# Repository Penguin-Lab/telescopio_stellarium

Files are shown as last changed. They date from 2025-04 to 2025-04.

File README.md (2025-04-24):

# Automação de telescópio para acompanhamento de corpos celestes com dados vindos do Stellarium
Neste projeto, um telescópio manual na configuração Azimutal foi automatizado para que fosse possível ajustar os ângulos de azimute e altitude a partir de dados do software Stellarium. Abaixo, é possível ver o sistema embarcado no telescópio.

 <p>
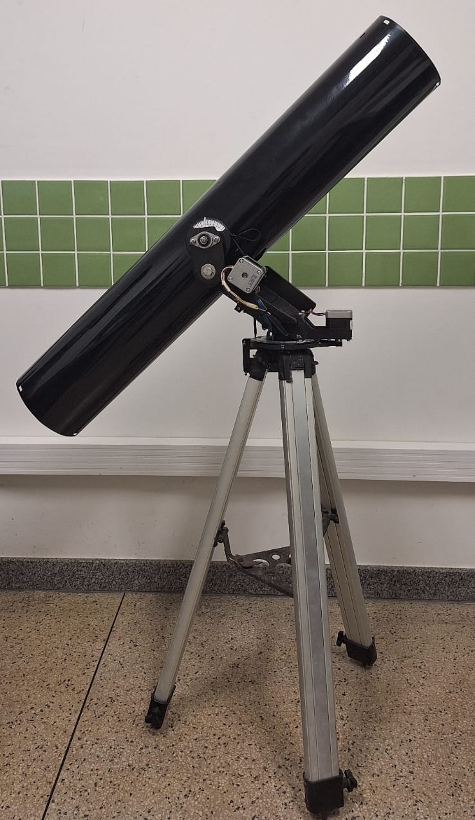
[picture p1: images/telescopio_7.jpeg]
  
</p>

<p>
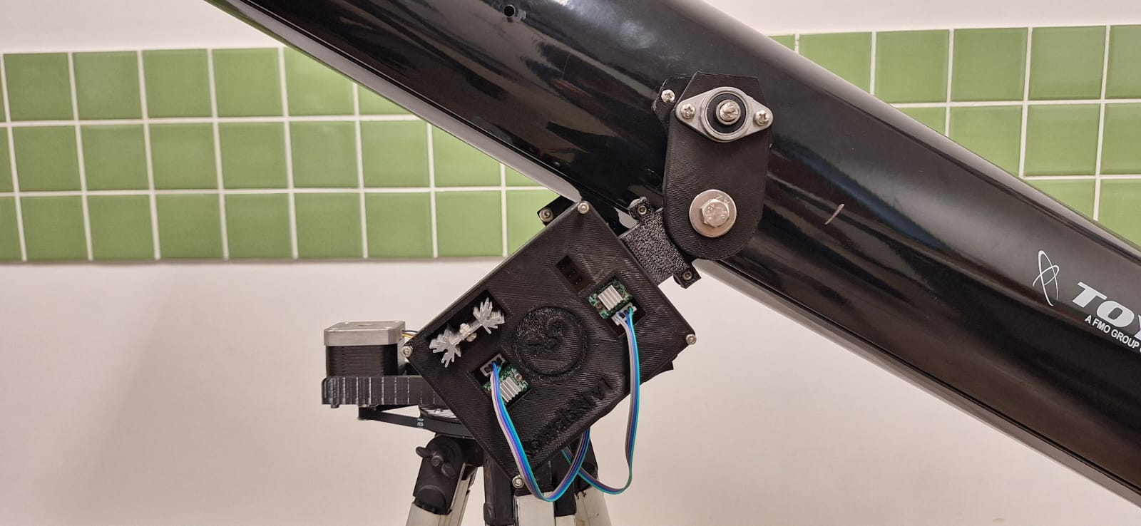
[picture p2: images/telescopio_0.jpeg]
  <br>
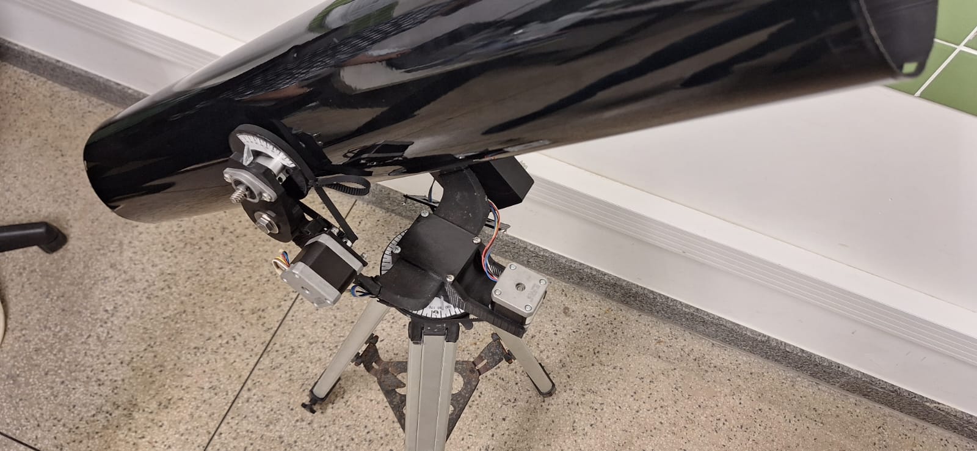
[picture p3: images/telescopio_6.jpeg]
  
</p>

# Estrutura física
A estrutura física da automação do telescópio é composta por três partes: a engrenagem e motor para controle do ângulo de altitude; a engrenagem e motor para controle do ângulo de azimute; e a caixinha com a placa de circuito impresso com a ESP32, que recebe os dados do Stellarium por Wi-fi e comanda os motores. Os dois motores de passo da estrutura são comandados pela ESP32 de 38 pinos por meio de um driver A4988. Todas as peças são projetadas em 3D e foram impressas em PLA, podendo ser encontradas na pasta pecas_3d deste projeto.

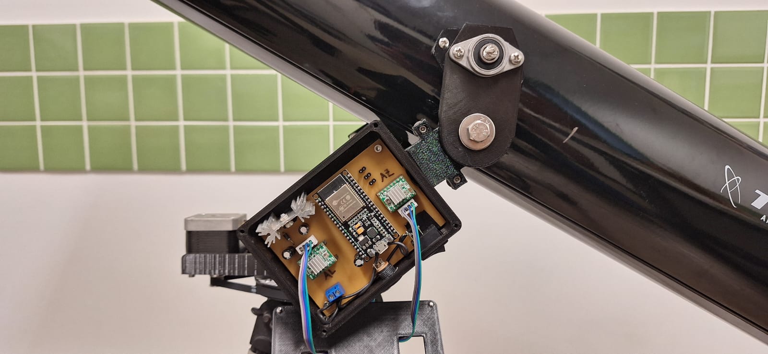
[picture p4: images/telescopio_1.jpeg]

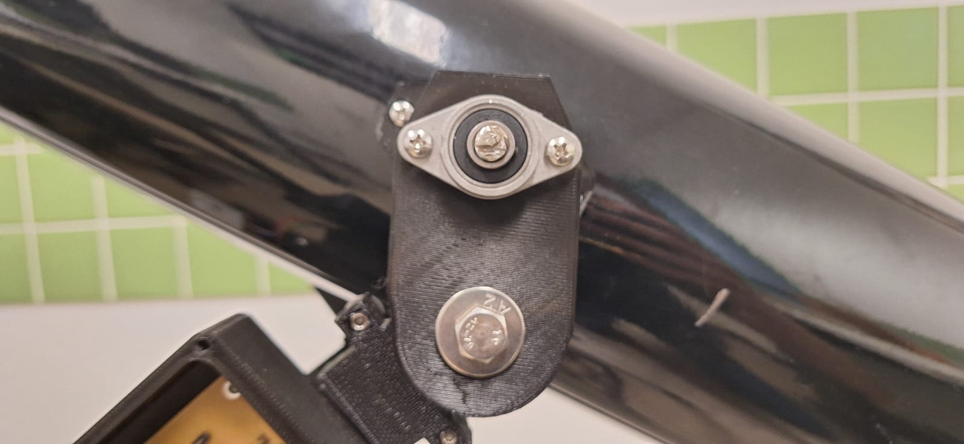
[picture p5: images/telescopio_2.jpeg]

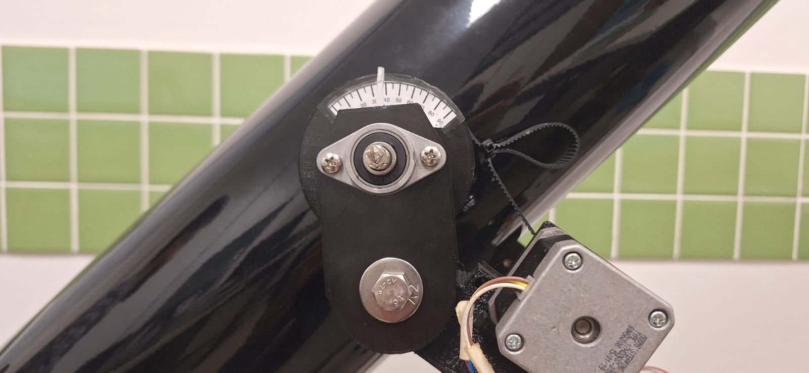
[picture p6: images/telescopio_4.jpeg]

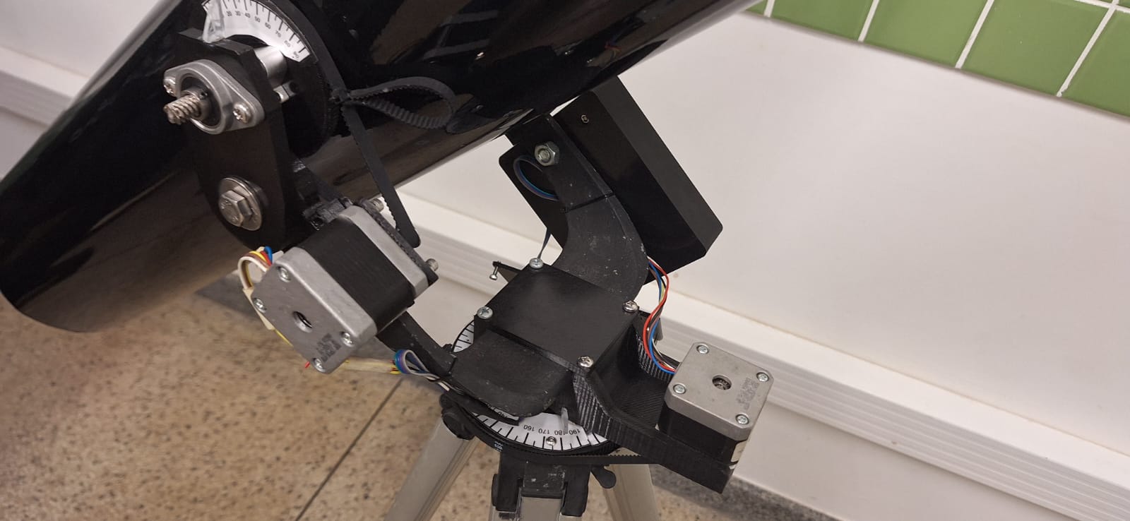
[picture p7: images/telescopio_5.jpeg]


Para iniciar o sistema, o telescópio, atualmente, deve ser posicionado virado para o Norte e seus ângulos (mostrados nos marcadores de papel) devem estar em 0°. Depois disso, deve-se enviar o código para a ESP32 com o IP correto do computador que está rodando o servidor do Stellarium e então liga-se o sistema por meio e uma chave abaixo da caixinha. O telescópio é alimentado por uma fonte de 12V.

# Software
Na pasta de códigos, há o código de programação da ESP32 (38 pinos). Este é um exemplo em C++ com multitask para o comando dos motores a partir dos dados do Stelarium. A ESP32 receberá as informações de altitude e azimute de um corpo celeste que o usuário do Stellarium clicou sobre.

# Configuração do Stellarium
Para esta solução proposta, foi utilizada a [API do Stellarium](https://stellarium.org/doc/23.0/remoteControlApi.html) em que os dados de corpos celestes são recebidos por meio de uma requisição HTTP. Vamos ver os passos para configurar o Stellarium:
* Instale o [Stellarium](https://stellarium.org/)
* Instale o plugin RemoteControl:
  - Com o Stellarium aberto, ao pressionar a tecla F2, a janela de configuração é aberta. Nesse momento, deve-se selecionar a aba de plugins. Já na aba de plugins, seleciona-se o RemoteControl. Após selecionar o plugin desejado, marque a opção "Carregar ao iniciar". Agora, feche a janela e feche o programa.
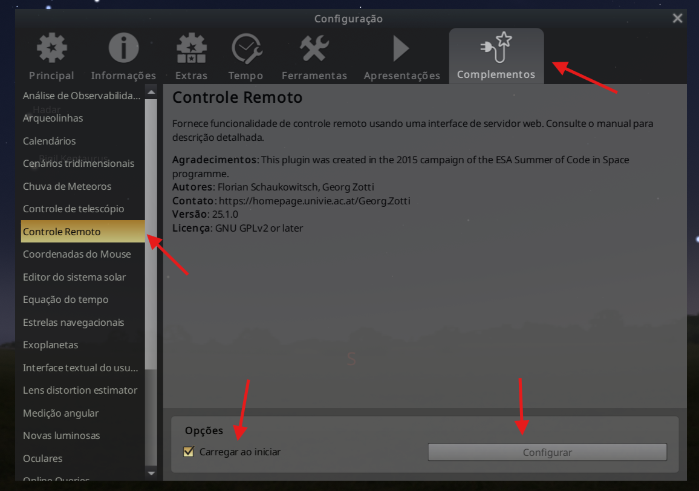
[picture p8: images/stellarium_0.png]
    
  - Ao reiniciar o Stellarium, entrando novamente na página do plugin RemoteControl, o botão "configurar" se torna disponível na interface do programa, sendo possível ajustar os parâmetros de acordo com a figura abaixo. Marque os dois pontos acima da janela, como mostra a figura e clique em Salvar Configurações. Agora, pode-se fechar a janela e fechar o programa.
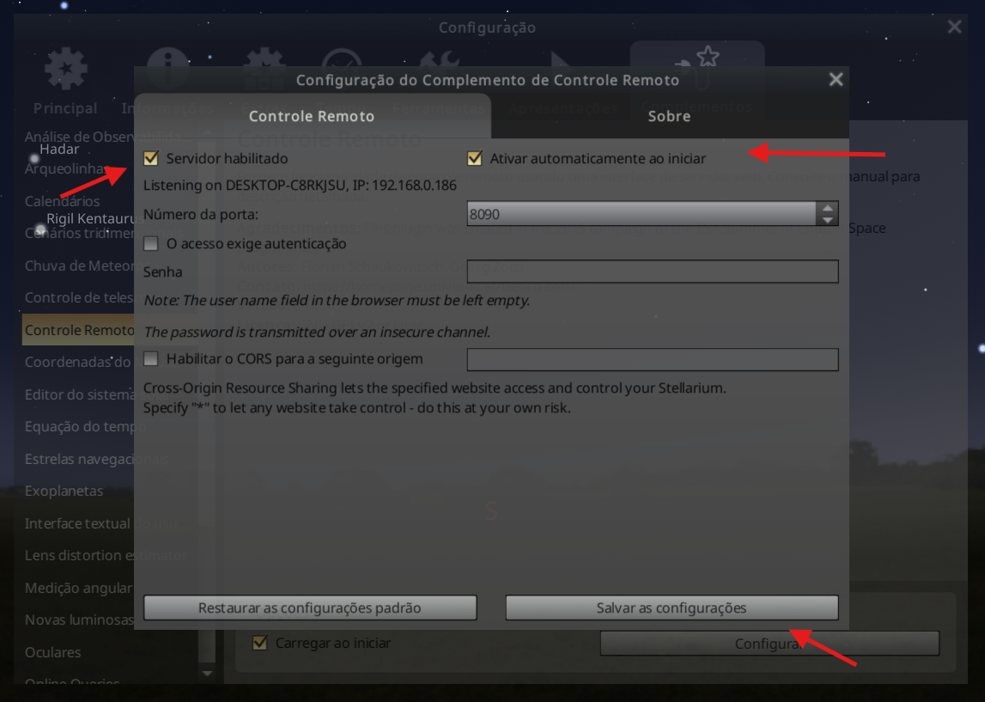
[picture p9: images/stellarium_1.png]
    
  - Agora, toda vez que abrir o Stellarium, ele funcionará como um servidor de acesso aos dados correntes dos corpos celestes apresentados por ele. Para que esses dados estejam relacionados corretamente com a sua localização geográfica, no menu do canto inferior esquerdo, abra a Janela de Localização (F6), pesquise o seu local para que no canto inferior apresente a sua posição geográfica corretamente.
  - Pronto! Basta agora clicar nos astros do Stellarium que a ESP32 já estará consumindo esses dados.

# Funcionamento da API do RemoteControl
A [API do RemoteControl do Stellarium](https://stellarium.org/doc/23.0/remoteControlApi.html) funciona na base de requisições HTTP. Ou seja, é possível usar a ESP32 ou qualquer linguagem que consiga realizar uma operação GET.HTTP para uma URL específica. Abaixo, é possível ver um exemplo do próprio site da API. Caso se queira receber dados atuais sobre a Lua, basta pedir um GET.HTTP para o link:

_http://localhost:8090/api/objects/info?name=moon&format=json_

ou

_http://localhost:8090/api/objects/info?name=lua&format=json_

Se jogar esse link no browse, é possível conferir o resultado desta requisição HTTP:

**{"above-horizon":false,"age":"26.16","airmass":-1,"albedo":0.11999999731779099,"altitude":-43.54344803507313,"altitude-geometric":-43.54344803507313,"ambientInt":0.054999977350234985,"ambientLum":0.0027867841999977827,"appSidTm":"8h50m29.5s","appSidTm-dd":132.6229148734547,"azimuth":245.27595169840848,"azimuth-geometric":245.27595169840848,"central_b":0.34271443620666603,"central_l":5.4017087382406395,"colongitude":90.04393694182852,"dec":-2.318601324208655,"decJ2000":-2.4583903909500355,"distance":0.0024639369185977277,"distance-km":368599.7165391639,"ecl-elongation":-0.7243564464838901,"ecl-elongation-deg":"-41.5026°","ecl-elongation-dms":"-41°30'09\"","ecliptic-obliquity":23.43598624024554,"elat":0.31553450590723886,"elatJ2000":0.31594411966903047,"elong":353.42953041853946,"elongJ2000":353.0758971843355,"elongation":0.7244721712882872,"elongation-deg":"41.5092°","elongation-dms":"+41°30'33\"","found":true,"glat":-59.15317236039611,"glong":82.73947535635295,"heliocentric-distance":1.00408417868352,"heliocentric-distance-km":150208855.12557617,"heliocentric-velocity":"[0.00952658, -0.0136085, 5.71737e-05]","heliocentric-velocity-kms":"28.76249","hourAngle-dd":138.7804304700692,"hourAngle-hms":"9h15m07.3s","iauConstellation":"Psc","illumination":12.61147403717041,"is-waning":true,"libration_b":0.34271443620666603,"libration_l":-5.4017087382406395,"localized-name":"Lua","meanSidTm":"8h50m29.5s","meanSidTm-dd":132.62288401855767,"name":"Moon","object-type":"moon","pa_axis":338.204304094815,"parallacticAngle":121.72861493520773,"penumbral-eclipse-magnitude":0,"phase":0.12611474096775055,"phase-angle":2.4154941734967172,"phase-angle-deg":"138.3976°","phase-angle-dms":"+138°23'51\"","phase-name":"Lua minguante","ra":-6.15751559661449,"raJ2000":-6.482643384375062,"rise":"2h26m","rise-dhr":2.4252777777777776,"scale":1,"set":"15h06m","set-dhr":15.093611111111112,"sglat":18.72705971457184,"sglong":288.2637687915038,"size":0.009426958597546628,"size-dd":0.5401249412839874,"size-deg":"0.54012°","size-dms":"+0°32'24.45\"","subsolar_b":0.9546297201113992,"subsolar_l":144.23647163485037,"transit":"8h48m","transit-dhr":8.806666666666667,"type":"Planet","umbral-eclipse-magnitude":0,"velocity":"[3.94235e-05, 0.000619631, 5.63846e-05]","velocity-kms":"1.07946","vmag":-7.989984035491943,"vmage":-7.780420780181885}**

A ESP32 pega exatamente a informação que se deseja ao se utilizar uma biblioteca de JSON para se acessar exatamente a informação. Por exemplo, caso se queira pegar o ângulo de azimute, pode-se utilizar as seguintes linhas de código (com a biblioteca de JSON: Arduino_JSON.h):

<p>
JSONVar info_astro = JSON.parse(payload);
</p>
<p>
az = info_astro["azimuth"];
</p>

# Referências
<p> [Stellarium](https://stellarium.org/) </p>
<p> [API do Stellarium](https://stellarium.org/doc/23.0/remoteControlApi.html) </p>
<p> [Explicação sobre como configurar o RemoteControl do Stellarium](https://devgirlunderscore.medium.com/how-to-use-stellarium-http-api-f0942d2c8820) </p>

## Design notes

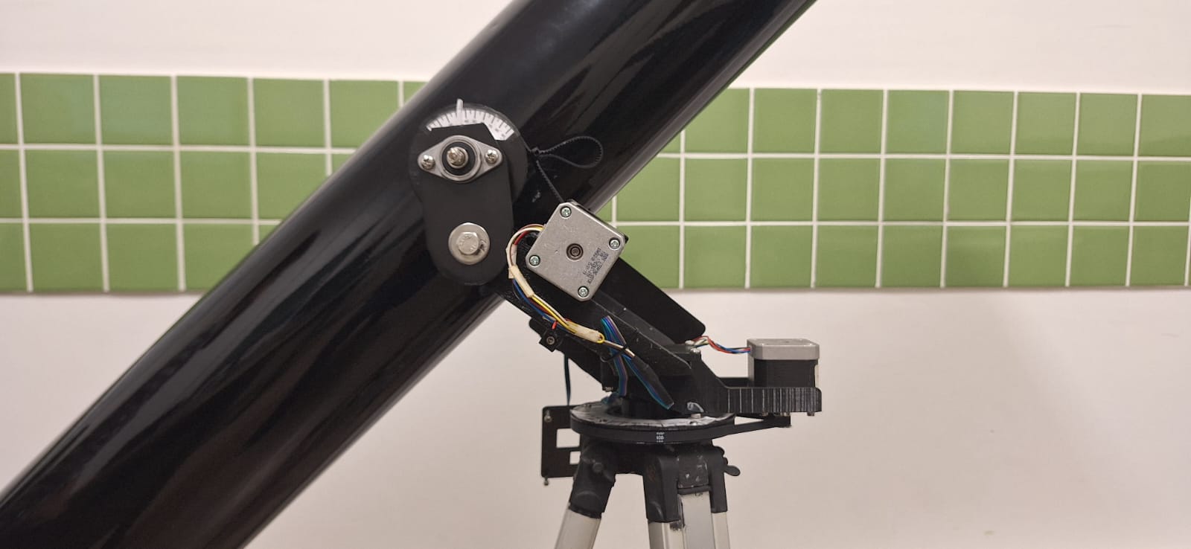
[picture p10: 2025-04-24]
images/telescopio_3.jpeg

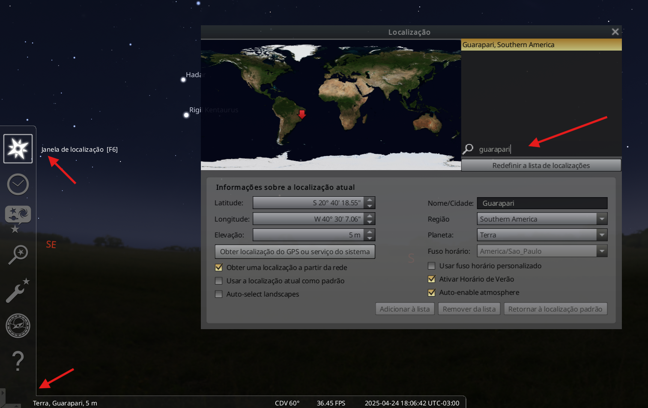
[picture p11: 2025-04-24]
images/stellarium_2.png

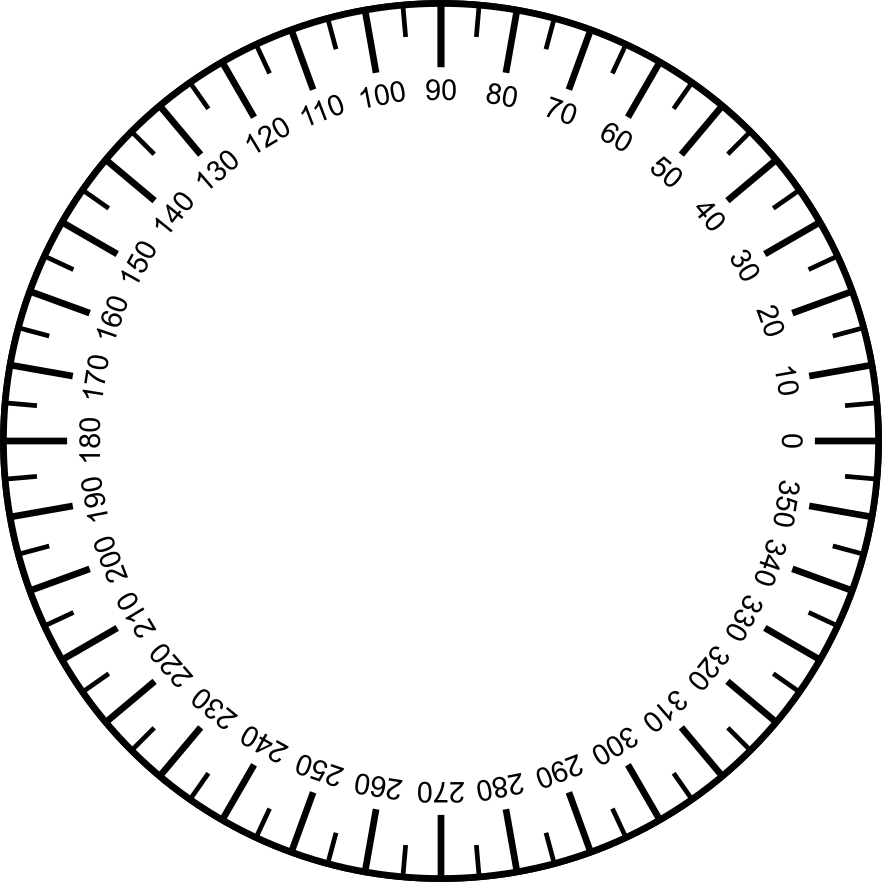
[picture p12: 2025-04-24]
pecas_3d/transferidor360.png

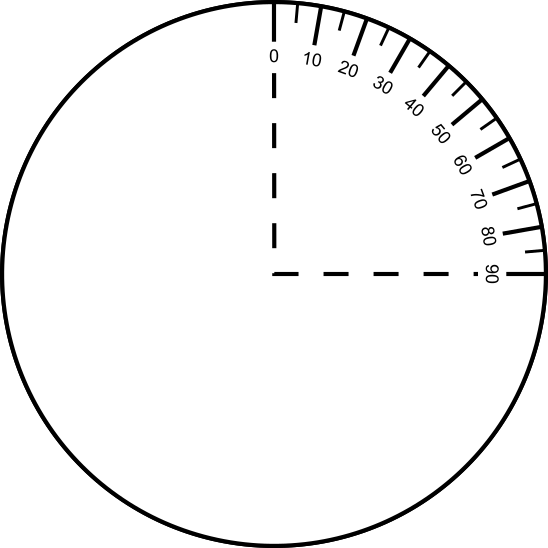
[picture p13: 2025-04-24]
pecas_3d/transferidor90.png

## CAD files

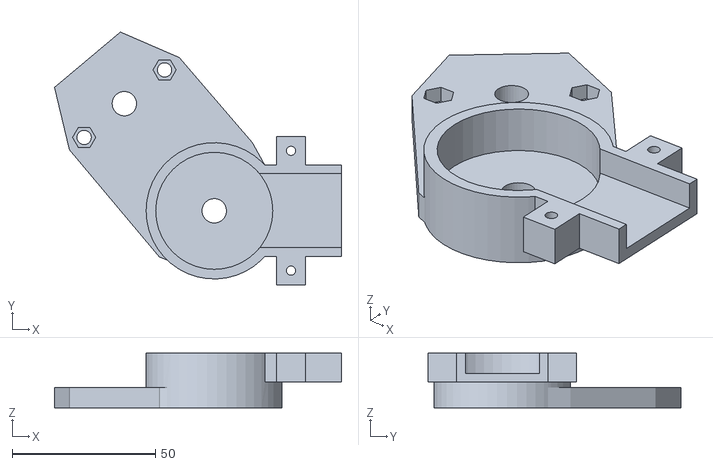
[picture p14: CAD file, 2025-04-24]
pecas_3d/suporte_tubo_sem_motor.STL
100.0 x 88.1 x 19.0

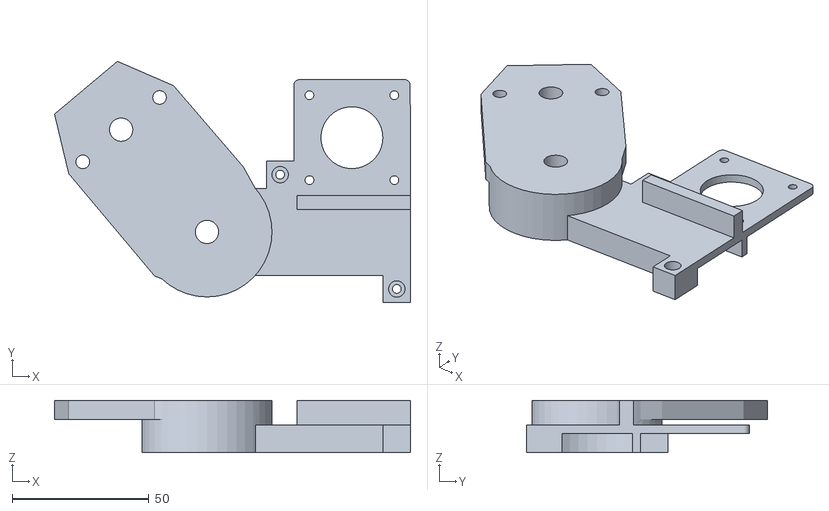
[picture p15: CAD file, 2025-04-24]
pecas_3d/suporte_tubo.STL
130.0 x 88.1 x 19.0

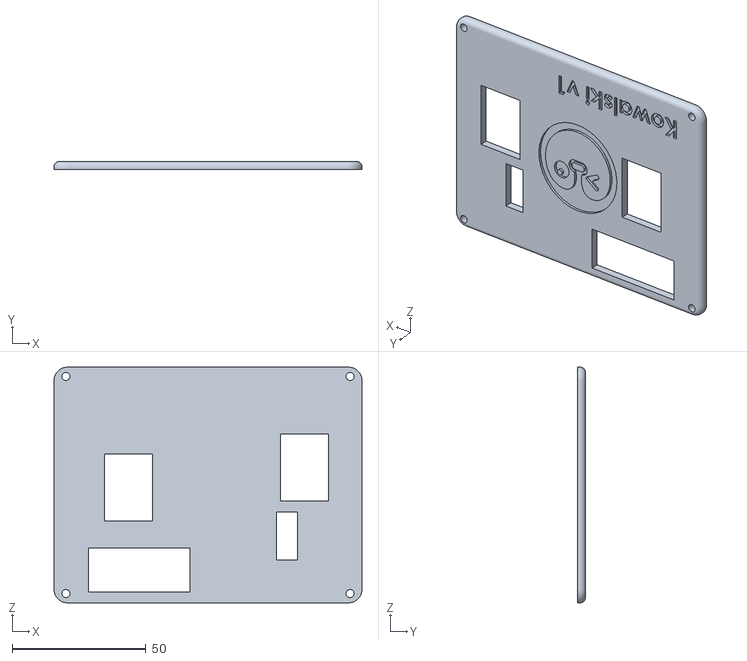
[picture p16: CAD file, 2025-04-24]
pecas_3d/caixa_PCI_tampa.STL
115.0 x 3.00 x 88.0

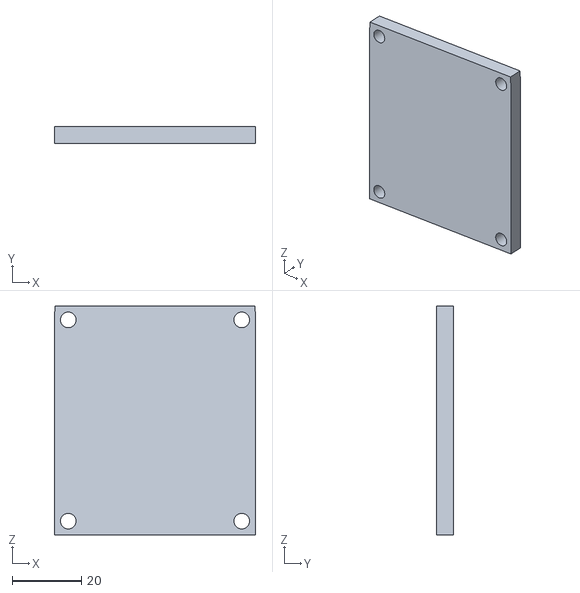
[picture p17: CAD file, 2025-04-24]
pecas_3d/azimute_suporte_motor_tampa.STL
58.0 x 5.00 x 66.0

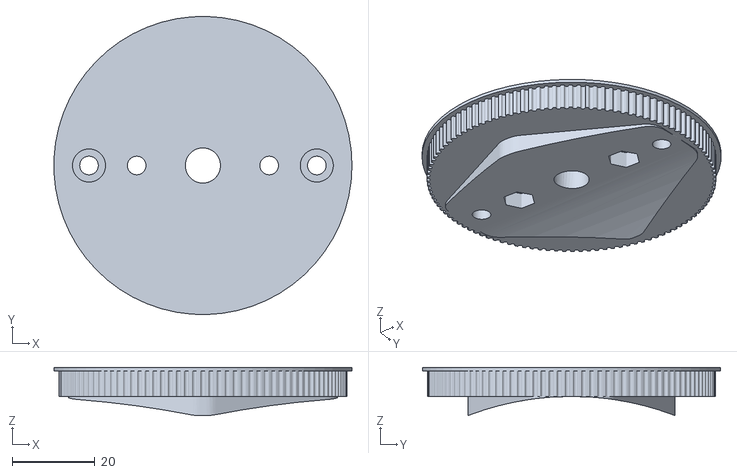
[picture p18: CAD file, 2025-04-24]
pecas_3d/presilha_tubo_engrenagem.STL
72.0 x 72.0 x 11.6

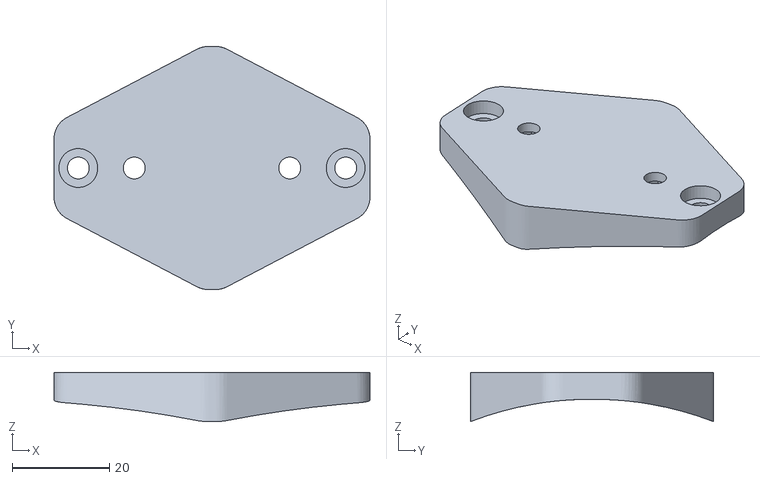
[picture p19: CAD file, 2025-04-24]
pecas_3d/presilha_tubo_MENOR.STL
65.0 x 50.0 x 10.1

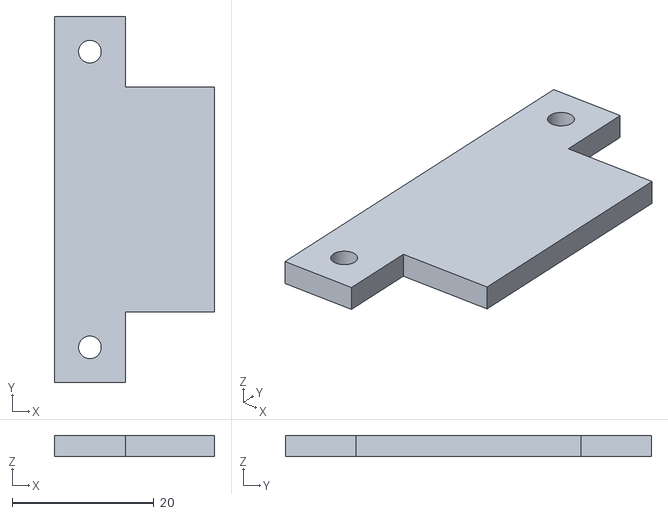
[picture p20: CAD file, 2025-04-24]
pecas_3d/suporte_tubo_tampa_sem_motor.STL
22.6 x 51.8 x 3.00

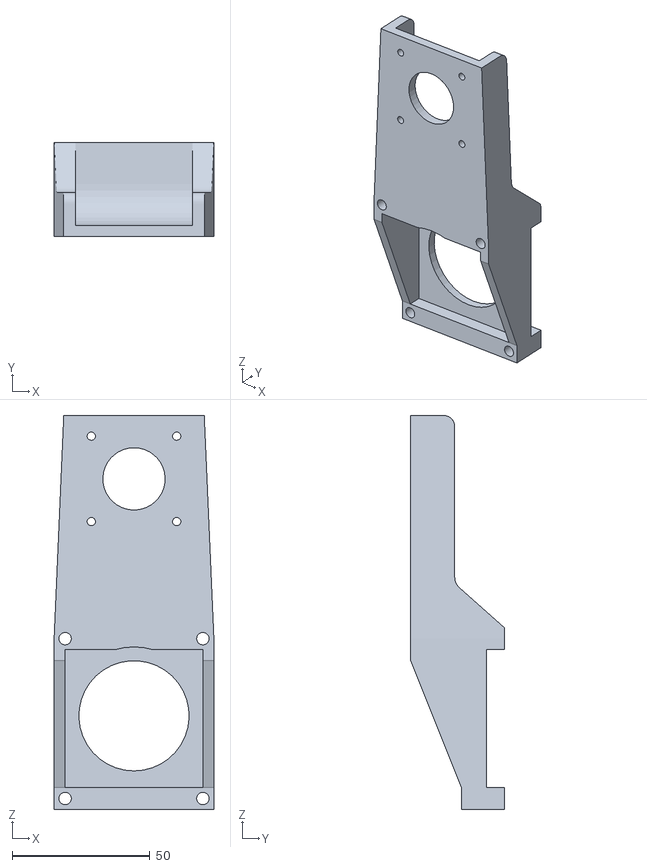
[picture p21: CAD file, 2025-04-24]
pecas_3d/azimute_suporte_motor.STL
58.0 x 34.0 x 143.0

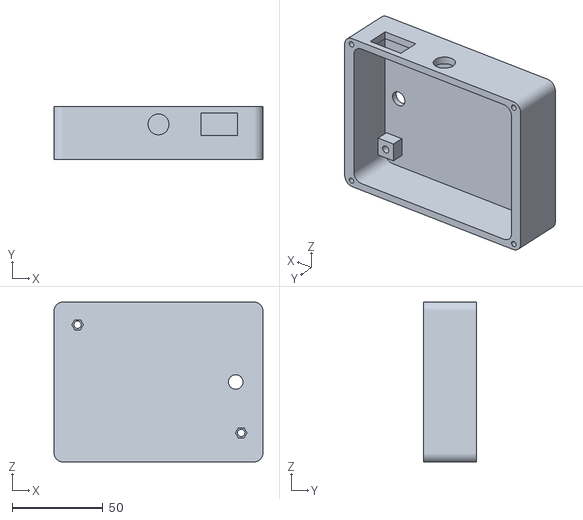
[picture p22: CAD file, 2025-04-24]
pecas_3d/caixa_PCI.STL
115.0 x 29.0 x 88.0

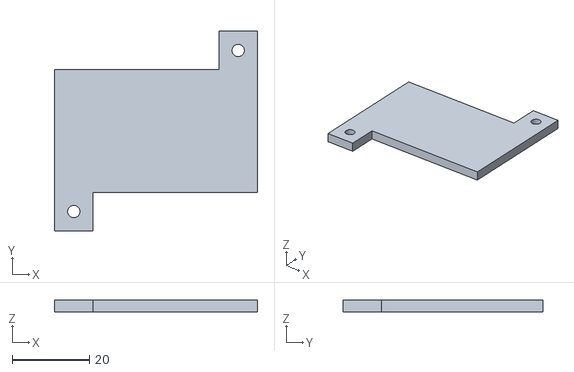
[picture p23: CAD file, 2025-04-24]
pecas_3d/suporte_tubo_tampa.STL
52.6 x 51.8 x 3.00

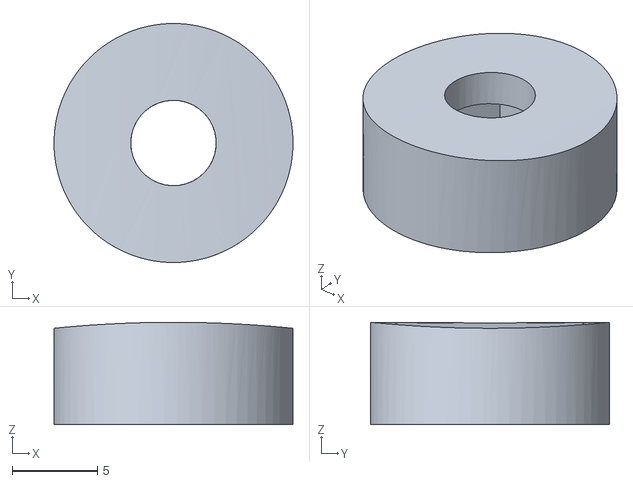
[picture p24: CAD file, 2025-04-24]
pecas_3d/Porta_Porca_tubo.STL
14.0 x 14.0 x 6.00

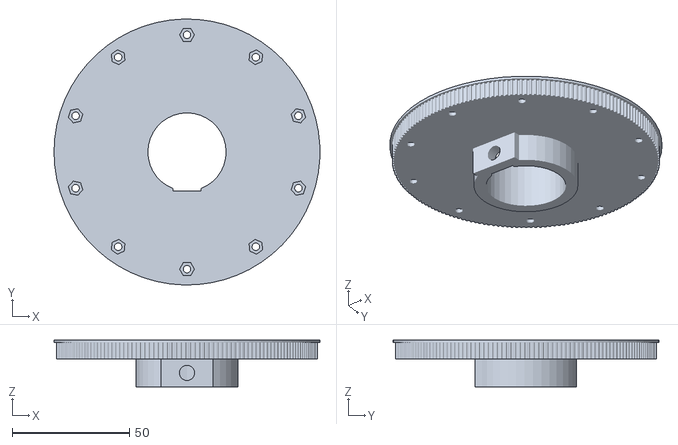
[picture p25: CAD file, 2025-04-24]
pecas_3d/azimute_engrenagem.STL
113.5 x 113.5 x 20.0

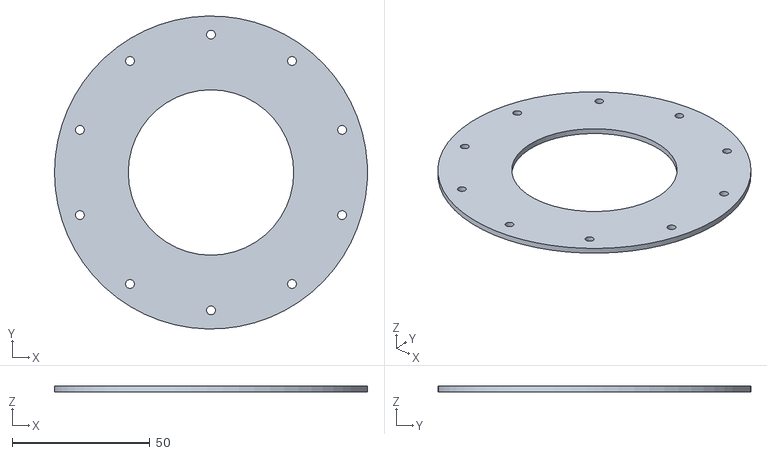
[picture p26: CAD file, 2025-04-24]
pecas_3d/azimute_tampa_engrenagem.STL
113.5 x 113.5 x 2.00

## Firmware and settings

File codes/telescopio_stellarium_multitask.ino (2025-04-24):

//https://devgirlunderscore.medium.com/how-to-use-stellarium-http-api-f0942d2c8820
//https://stellarium.org/doc/23.0/remoteControlApi.html

#include <WiFi.h>
#include <HTTPClient.h>
#include <Arduino_JSON.h>

//Tasks
void TaskClique(void *pvParameters);
void TaskAstro(void *pvParameters);
void TaskMotorAl(void *pvParameters);
void TaskMotorAz(void *pvParameters);

//Motor Az
const int PINDirAz = 17;
const int PINStepAz = 16;
const int PINEnableAz = 15;
const int PINMS1Az =2;
const int PINMS2Az = 0;
const int PINMS3Az = 4;
const int steps_pv_Az = 35200;
double az = 0;
int MeioPeriodoAz=1;
long passosAz = 0;

//Motor Al
const int PINDirAl = 33;
const int PINStepAl = 25;
const int PINEnableAl = 12;
const int PINMS1Al =14;
const int PINMS2Al = 27;
const int PINMS3Al = 26;
const int steps_pv_Al = 24000;
double al = 0;
int MeioPeriodoAl=5;
long passosAl = 0;

//Wifi
const char* ssid = "wifizinho"; //Nome do seu Wifi
const char* password = "senha123"; //Senha do Wifi
String astro = "";
String server_ip = "192.168.11.154"; //Infelizmente, voce ainda tem que colocar o IP do computador toda vez antes de usar o telescopio
String url = "http://"+server_ip+":8090/api/objects/info?name="+astro+"&format=json";
String url_clique = "http://"+server_ip+":8090/api/main/status?actionId=0&propId=0&format=json";
bool connectWifi();
bool wifiConnected = false;

//Http
HTTPClient http_clique, http;
String payload;

void setup() {
  // Motor Az
  pinMode(PINDirAz,OUTPUT);
  pinMode(PINStepAz,OUTPUT);
  pinMode(PINMS1Az,OUTPUT);
  pinMode(PINMS2Az,OUTPUT);
  pinMode(PINMS3Az,OUTPUT);
  pinMode(PINEnableAz,OUTPUT);
  digitalWrite(PINEnableAz,LOW);
  digitalWrite(PINMS1Az,HIGH);
  digitalWrite(PINMS2Az,HIGH);
  digitalWrite(PINMS3Az,HIGH);

  // Motor Al
  pinMode(PINDirAl,OUTPUT);
  pinMode(PINStepAl,OUTPUT);
  pinMode(PINMS1Al,OUTPUT);
  pinMode(PINMS2Al,OUTPUT);
  pinMode(PINMS3Al,OUTPUT);
  pinMode(PINEnableAl,OUTPUT);
  digitalWrite(PINEnableAl,LOW);
  digitalWrite(PINMS1Al,HIGH);
  digitalWrite(PINMS2Al,HIGH);
  digitalWrite(PINMS3Al,HIGH);
  
  Serial.begin(115200);

  wifiConnected = connectWifi();

  while (!wifiConnected) {
    Serial.println("Cannot connect to WiFi. Please check data and reset the ESP.");
    delay(2000);
    wifiConnected = connectWifi();
  }

  http_clique.begin(url_clique.c_str()); //Specify the URL and certificate
  http_clique.setFollowRedirects(HTTPC_STRICT_FOLLOW_REDIRECTS);

  // Task Config
  xTaskCreatePinnedToCore(
    TaskClique
    ,  "TaskClique"
    ,  10000
    ,  NULL
    ,  1
    ,  NULL
    ,  1); //0 ou 1
    
  xTaskCreatePinnedToCore(
    TaskAstro
    ,  "TaskAstro"
    ,  5000
    ,  NULL
    ,  1
    ,  NULL
    ,  1); //0 ou 1
    
  xTaskCreatePinnedToCore(
    TaskMotorAl
    ,  "TaskMotorAl"
    ,  2048
    ,  NULL
    ,  1
    ,  NULL
    ,  1); //0 ou 1
  
  xTaskCreatePinnedToCore(
    TaskMotorAz
    ,  "TaskMotorAz"
    ,  2048
    ,  NULL
    ,  1
    ,  NULL
    ,  1); //0 ou 1
}

void loop() {
  vTaskDelay(pdMS_TO_TICKS(10000));
}

void TaskClique(void *pvParameters){
  for(;;) {
    int httpCode = http_clique.GET();
    if (httpCode == 200){
      payload = http_clique.getString();
      Serial.println(payload);
      JSONVar informacao = JSON.parse(payload);//mudar
      if (JSON.typeof(informacao) == "undefined"){
       Serial.println("Parsing input failed!");
      }
      else{
        Serial.println("Parsing input ok!");
        String texto = payload;//informacao["selectioninfo"];
        if (!texto.isEmpty()){
          int ini = texto.indexOf("selectioninfo\":\"<h2>");
          if (ini != -1){
            //Serial.print(ini);
            //Serial.print(" ");
            int fim = texto.indexOf("</h2>",ini);
            if (fim != -1){
              //Serial.print(fim);
              //Serial.print(" ");
              String astro_novo = texto.substring(ini+4+16,fim);
              fim = astro_novo.indexOf(" ");
              if (fim != -1){
                astro_novo = astro_novo.substring(0,fim);
              }
              fim = astro_novo.indexOf("(");
              if (fim != -1){
                astro_novo = astro_novo.substring(0,fim);
              }
              fim = astro_novo.indexOf("<");
              if (fim != -1){
                astro_novo = astro_novo.substring(0,fim);
              }
              //Serial.println(fim);
              //verificar catalogo
              if (astro != astro_novo){
                astro = astro_novo;
                Serial.println(astro);
                http.end();
                url = "http://"+server_ip+":8090/api/objects/info?name="+astro+"&format=json";
                http.begin(url.c_str()); //Specify the URL and certificate
                http.setFollowRedirects(HTTPC_STRICT_FOLLOW_REDIRECTS);
              }
            }
          }
        }
      }
    }
    else{
      Serial.print("Httpcode invalido: ");
      Serial.println(httpCode);
    }
    vTaskDelay(pdMS_TO_TICKS(500));
  }
}

void TaskAstro(void *pvParameters){
  for(;;) {
    if (astro != ""){
      int httpCode2 = http.GET();
      if (httpCode2 == 200){
        payload = http.getString();
        JSONVar info_astro = JSON.parse(payload);
        if (JSON.typeof(info_astro) == "undefined"){
          Serial.println("Parsing 2 input failed!");
        }
        else{
          az = info_astro["azimuth"];
          az = 360.0-double(az);
          Serial.print(az);
          Serial.print(" - ");
          al = info_astro["altitude"];
          Serial.println(al);
          al = double(al);
        }
      }
      else{
        Serial.print("Httpcode invalido: ");
        Serial.println(httpCode2);
      }
    }
    vTaskDelay(pdMS_TO_TICKS(50));
  }
}

void TaskMotorAl(void *pvParameters){
  for(;;) {
    long passos_desejados = long(al*(double(steps_pv_Al)/360.0));
    if (passos_desejados>passosAl){
      digitalWrite(PINDirAl,LOW);
      digitalWrite(PINStepAl,HIGH);
      delay(MeioPeriodoAl);
      digitalWrite(PINStepAl,LOW);
      passosAl++;
      vTaskDelay(pdMS_TO_TICKS(MeioPeriodoAl));
    }
    else if (passos_desejados<passosAl){
      digitalWrite(PINDirAl,HIGH);
      digitalWrite(PINStepAl,HIGH);
      delay(MeioPeriodoAl);
      digitalWrite(PINStepAl,LOW);
      passosAl--;
      vTaskDelay(pdMS_TO_TICKS(MeioPeriodoAl));
    }
  }
}

void TaskMotorAz(void *pvParameters){
  for(;;) {
    long passos_desejados = long((az)*(double(steps_pv_Az)/360.0));
    if (passos_desejados>passosAz){
      long d1 = passos_desejados-passosAz;
      long d2 = passosAz+(steps_pv_Az-passos_desejados);
      Serial.print(passos_desejados);
      Serial.print(" - ");
      Serial.print(passosAz);
      Serial.print(" - ");
      Serial.print(d1);
      Serial.print(" - ");
      Serial.println(d2);
      if (d1<d2){
          digitalWrite(PINDirAz,LOW);
          digitalWrite(PINStepAz,HIGH);
          delay(MeioPeriodoAz);
          digitalWrite(PINStepAz,LOW);
          passosAz++;
          if(passosAz>(steps_pv_Az-1)){
            passosAz = 0;
          }
          // Serial.println("A");
          vTaskDelay(pdMS_TO_TICKS(MeioPeriodoAz));
          }
        else{
        digitalWrite(PINDirAz,HIGH);
        digitalWrite(PINStepAz,HIGH);
        delay(MeioPeriodoAz);
        digitalWrite(PINStepAz,LOW);
        passosAz--;
        if(passosAz<0){
            passosAz = steps_pv_Az-1;
          }
          // Serial.println("B");
        vTaskDelay(pdMS_TO_TICKS(MeioPeriodoAz));
        }
       }
        else if(passosAz>passos_desejados){
            long d1 = passosAz-passos_desejados;
            long d2 = passos_desejados+(steps_pv_Az-passosAz);
            Serial.print(passos_desejados);
            Serial.print(" - ");
            Serial.print(passosAz);
            Serial.print(" - ");
            Serial.print(d1);
            Serial.print(" - ");
            Serial.println(d2);
            if (d2<d1){
              digitalWrite(PINDirAz,LOW);
              digitalWrite(PINStepAz,HIGH);
              delay(MeioPeriodoAz);
              digitalWrite(PINStepAz,LOW);
              passosAz++;
              if(passosAz>(steps_pv_Az-1)){
                passosAz = 0;
              }
          // Serial.println("C");
              vTaskDelay(pdMS_TO_TICKS(MeioPeriodoAz));
              }
            else {
              digitalWrite(PINDirAz,HIGH);
              digitalWrite(PINStepAz,HIGH);
              delay(MeioPeriodoAz);
              digitalWrite(PINStepAz,LOW);
              passosAz--;
              if(passosAz<0){
                passosAz = steps_pv_Az-1;
              }
          // Serial.println("D");
              vTaskDelay(pdMS_TO_TICKS(MeioPeriodoAz));
              }
             }
     
  }
}

bool connectWifi(){
  bool state = true;
  int i = 0;
  
  WiFi.mode(WIFI_STA);
  WiFi.begin(ssid, password);
  Serial.println("");
  Serial.println("Connecting to WiFi");
  Serial.print("Connecting...");
  while (WiFi.status() != WL_CONNECTED) {
    delay(500);
    Serial.print(".");
    if (i > 20){
      state = false; break;
    }
    i++;
  }
  Serial.println("");
  if (state){
    Serial.print("Connected to ");
    Serial.println(ssid);
    Serial.print("IP address: ");
    Serial.println(WiFi.localIP());
  }
  else {
    Serial.println("Connection failed.");
  }
  return state;
}
